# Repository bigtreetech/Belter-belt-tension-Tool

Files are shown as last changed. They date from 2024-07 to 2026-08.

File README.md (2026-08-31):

# BIQU Belter

Belter is a digital belt tension measurement tool for 3D printers, designed for belt setup, belt matching, and repeat adjustment.

## Quick Links

- **Product Link:** [BIGTREETECH Official Website](https://biqu.equipment/products/biqu-belter-belt-tension-tool)
- **Belter Calculation Tool:** [belter.bttwiki.com](https://belter.bttwiki.com/)
- **Calibration / Usage Guide:** [Belter Wiki](https://global.bttwiki.com/belter.html)
- **GitHub Link:** [bigtreetech/Belter-belt-tension-Tool](https://github.com/bigtreetech/Belter-belt-tension-Tool)

## Calibration & Calculation

The latest Belter workflow includes:

- Basic Belter calibration using **Belter Calibration Reading** and **Belt Thickness**
- **Compare Belts** and **Single Belt** measurement modes
- A default nonlinear tension model for normal use
- Optional **Calculation Model Calibration** using 500–2000 g test data for users who want the best possible absolute tension accuracy
- Preset or custom tension ranges in the Web Tool

For most users:

`Calibrate Belter → Measure Belts Normally`

For advanced users:

`Calibrate Belter → Optional Calculation Model Calibration → Measure Belts Normally`

## Repository Contents

- [`Calculation Tool`](./Calculation%20Tool/) — calculation and calibration resources
- [`Manual`](./Manual/) — English and Chinese Belter manuals
- [`PrintParts`](./PrintParts/) — STEP files for the Hand Held Bracket, Plunger, and ProbeTip
- [`LICENSE.md`](./LICENSE.md) — license information



## Copyright

These files and the designs contained therein are copyright (c) 2026 BIQU.

These files and the designs contained therein are additionally licensed under **CC-BY-NC-ND-4.0**.

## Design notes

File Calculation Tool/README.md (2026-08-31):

New calculator and calibration workflow are now available

## Belter Calculator & Documentation Update

We’ve made a major update to the **BIQU Belter calculation workflow, Web Tool, and documentation** based on community feedback and additional testing.

### What’s New

- **Updated tension calculation model**
  - The calculator now uses the nonlinear model:
    `Tension = A / (dmax - d)^p`
  - Default parameters have been updated 

- **Custom calculation model calibration**
  - Advanced users can now generate their own **Coefficient A** and **Exponent p** from real test data.
  - The Web Tool supports test loads from **500 g to 2000 g in 100 g increments**.
  - The fitted model automatically reports **R²** and **RMSE** for reference.

- **Calibration data spreadsheet**
  - A new spreadsheet is provided for recording repeated measurements.
  - Each load can be measured **12 times**.
  - The highest and lowest readings are automatically removed.
  - The remaining 10 readings are used to calculate **Average (trimmed 10)** and **StDev**.

- **Direct Excel → Web Tool data import**
  - Copy the complete **Average (trimmed 10)** row from the calibration spreadsheet.
  - Paste it into any field under **Fit Parameters from Test Data**.
  - The Web Tool automatically maps the values from **500 g → 2000 g** and runs the model fit.

- **Custom Tension Range**
  - The previous **Belt Width** setting has been updated to **Tension Range**.
  - Existing presets remain unchanged:
    - GT2 6 mm
    - GT2 9 mm
  - A new **Custom Range** option allows users to define their own **Min / Max tension** values.

- **English / Chinese language support**
  - The Web Tool can now be switched directly between **English and Chinese**.

- **Updated calibration workflow**
  - Normal Belter calibration remains simple.
  - Custom calculation model calibration is an **optional advanced step**.
  - Users who do not need a custom model can continue using the default calculation parameters.

### Recommended Workflow

`Calibrate Belter → [Optional] Calibrate Calculation Model → Measure Belts Normally`

The goal of this update is to make the Belter workflow more transparent, repeatable, and flexible while keeping normal day-to-day measurements simple.

Special thanks to **@rongith** for providing experimental measurement data and to **@anokfireball** for contributing to the nonlinear tension model and technical discussion.

We’ll continue improving the Belter workflow based on real-world testing and community feedback.

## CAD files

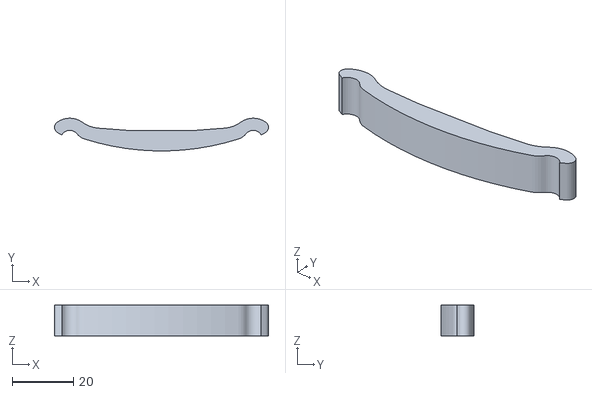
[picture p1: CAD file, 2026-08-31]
Calculation Tool/BIQU Belter Zeroing tool.STL
70.0 x 10.7 x 10.0

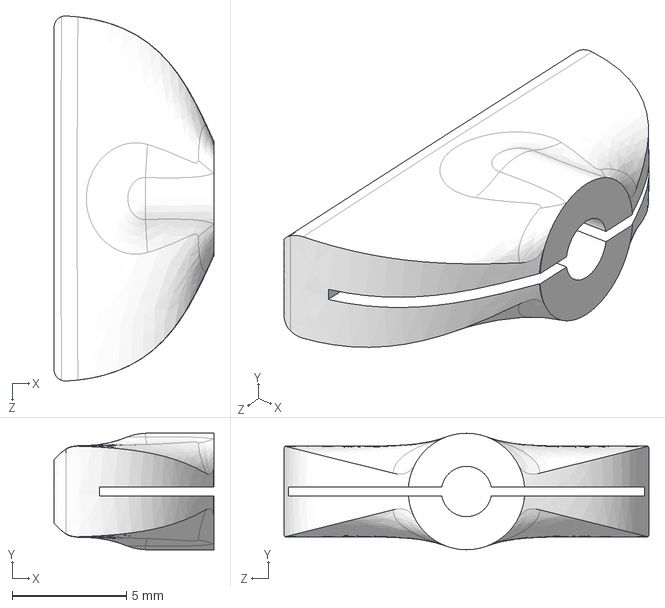
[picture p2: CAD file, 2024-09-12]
PrintParts/ProbeTip.STEP
7.00 x 5.10 x 16.0 mm

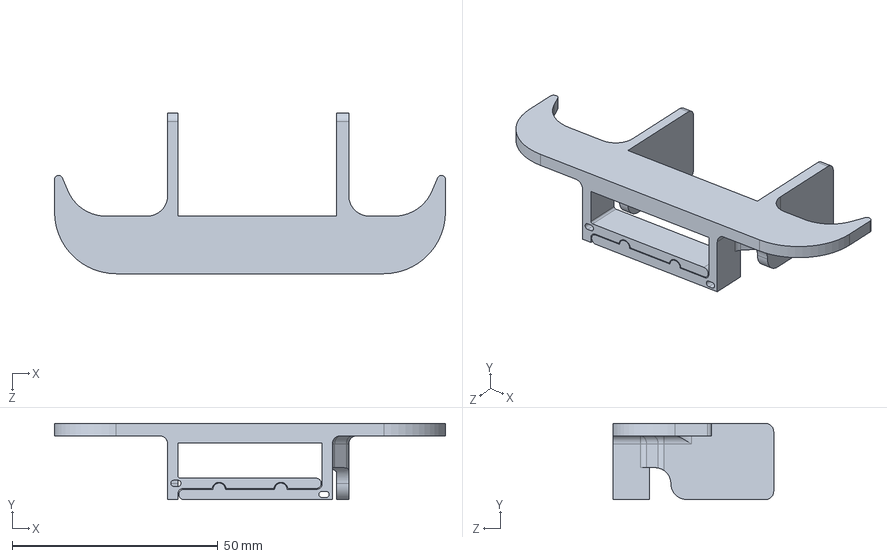
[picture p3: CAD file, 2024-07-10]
PrintParts/Hand Held bracket.STEP
95.0 x 18.5 x 39.0 mm

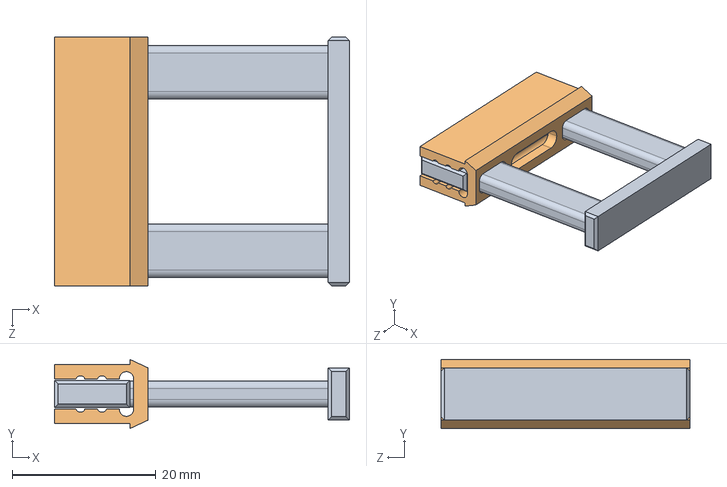
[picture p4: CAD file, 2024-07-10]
PrintParts/Plunger.STEP
41.0 x 9.60 x 34.6 mm

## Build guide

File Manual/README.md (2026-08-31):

# BIQU Belter Manual

The latest Belter setup, calibration, and usage instructions are maintained on the BIQU Wiki.

## View the Online Manual

👉 **[Open the BIQU Belter Wiki](https://global.bttwiki.com/belter.html)**

For the latest instructions and updates, please refer to the online Wiki instead of the files in this folder.

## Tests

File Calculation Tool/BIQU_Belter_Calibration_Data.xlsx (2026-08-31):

BIQU Belter Measurement Data
Enter 12 readings for each load. Average and StDev automatically exclude one highest and one lowest reading, using the remaining 10 values.
Measurement / Load | 500 g | 600 g | 700 g | 800 g | 900 g | 1000 g | 1100 g | 1200 g | 1300 g | 1400 g | 1500 g | 1600 g | 1700 g | 1800 g | 1900 g | 2000 g
Measurement 1 | 3.820 | 4.300 | 4.600 | 4.820 | 5.120 | 5.280 | 5.620 | 5.620 | 5.820 | 5.710 | 6.000 | 5.910 | 6.080 | 6.070 | 6.160 | 6.180
Measurement 2 | 4.000 | 4.380 | 4.620 | 4.950 | 5.000 | 5.230 | 5.410 | 5.550 | 5.920 | 5.880 | 6.030 | 5.890 | 6.080 | 6.190 | 6.150 | 6.190
Measurement 3 | 4.050 | 4.330 | 4.700 | 4.920 | 5.230 | 5.260 | 5.390 | 5.670 | 5.720 | 5.870 | 5.810 | 5.960 | 6.030 | 6.070 | 6.140 | 6.220
Measurement 4 | 3.920 | 4.400 | 4.810 | 4.760 | 5.230 | 5.290 | 5.500 | 5.580 | 5.720 | 5.710 | 5.890 | 5.950 | 6.110 | 6.130 | 6.160 | 6.280
Measurement 5 | 4.080 | 4.460 | 4.780 | 4.820 | 5.210 | 5.210 | 5.530 | 5.520 | 5.840 | 5.780 | 6.010 | 5.990 | 6.070 | 6.070 | 6.190 | 6.240
Measurement 6 | 3.820 | 4.300 | 4.640 | 4.840 | 5.010 | 5.290 | 5.510 | 5.580 | 5.740 | 5.790 | 5.921 | 5.960 | 6.100 | 6.110 | 6.180 | 6.230
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

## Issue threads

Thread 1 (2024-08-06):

Additional readings/tension calculator for other belt types?

netweaver1970, 2024-08-06:
Hi, can you provide the calculator for GT3 belts as well? My Monolith upgrade for my V2.4 will use 6mm GT3 belts.

Thanks!

BTTJUSTIN, 2024-09-11:
Thanks for making this suggestion. We will discuss it internally and update the documentation if it is approved.

zlatkomos, 2024-12-01:
> Thanks for making this suggestion. We will discuss it internally and update the documentation if it is approved.

.... do you have any news on this issue?

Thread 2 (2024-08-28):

Verify Belt Tensions...

LostFool, 2024-08-28:
Voron 2.4 r1
350mm
z belts = LL-2GT RF

Literally not possible to get them to the recommended ~7.05mm deflection.
Stuck at ~5.8

How can we determine these numbers to create our own belt charts?

SamppaD78, 2024-09-11:
No problem. Lets wait and see what support has to say.

V8coyote43v3r, 2024-09-12:
Update the Belt Tension GT2 RF (N)  values in colum b with actual tension, everything else will change automatically.

BTTJUSTIN, 2024-09-12:
Please print and install ProbeTip.step to ensure accurate reading
https://github.com/bigtreetech/Belter-belt-tension-Tool/tree/master/PrintParts

SamppaD78, 2024-09-12:
Hi. Installed the printed part and still max deflection of the belts is at -7.02 thats about 19.98N. Spec value is  20.04-25.8
I tried the B colum update values but nothing changes for me,only when values are updated on the belter displayed values chart is that i get the reading for tension.

rongith, 2024-09-13:
I have completely different values for a corresponding table mm / N.

I attached spools of filament of different weight to a suspended belt. Here my results:
| Spool weight (kg) | Spool weight (N) | My deflection (mm) | Biqu deflection (mm) |
| --- | --- | --- | --- |
| 0.325 | 3.19 | 3 | 4.8 |
| 0.565 | 5.54 | 4.4 | 5.1 |
| 0.861 | 8.45 | 5.2 | 5.5 |
| 1.130 | 11.1 | 5.7 | 5.8 |
| 1.580 | 15.5 | 6.1 | 6.4 |
| 1.935 | 18.9 | 6.3 | 6.9 |
| 2.305 | 22.6 | 6.4 | 7.3 |
| 3.205 | 31.4 | 6.7 | 8.5 |
| 4.255 | 41.7 | 6.9 | 9.8 |
| infinity | infinity | 7.6 | infinity |

How can the tension be proportional to the deflection according to your calculation sheet (you found a linear regression)? How can you reach 12mm deflection (under 58N tension) as with a straight belt, the deflection would be 7.6mm, the maximum value?

According to your linear regression, 1000N would be 135mm of deflection.

Something is very wrong here or I didn't understand at all how your equipment run.

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

SamppaD78, 2024-09-14:
Hi. I'm not a expert on belt tension. This info is what tool and calculator is providing . I purchased this belt tool to use it with tensioning Voron 2.4R2 belts. Now there is definitely a issue, is it a user ,tool,or calculator provided related I don't know,but we are here to find out. How I use this tool, zero out the tool,attach the tool to the belt and get the reading from the tool. Tool display -7,01 with plunger attached to the tools shaft.
I open the belt tension calculator,under printer type and model column  select Voron Z belts,under  Belter displayed value mm column I added  tool displayed value -7.01 and press enter. Calculator  Belt tension column display value of 20,075. Recommended tension column is showing recommended tension value of min 20.4 and max value of 25.8 and  last column is reporting that belt tension is out of range.
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

I would like to find reason for this issue,so help is appreciated.

SamppaD78, 2024-09-14:
I got email reply from BTT tech support on this issue

[support01@bigtree-tech.com,]

Hello sir, I asked about this kind of situation. Because the printout is installed or the printout itself or even the probe itself has differences, the actual measurement value will be inaccurate. We will set a standard in the future. Please wait patiently.

Looking forward to your reply.

Best Regards

Biqu

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

rongith, 2024-09-14:
> I would like to find reason for this issue,so help is appreciated.

Yes for me there is something wrong in the Biqu methodology. I made myself some measure to ensure I have some reliable results.

And would you know the "needle" go as far as intended in the probe tip? You may have an offset.

I designed the joined part as a reference to check I got every time 7.6mm (in my case) before measuring the belt. That way and because I done my own reference measurement, I'm quite independent of the probe tip print. It is like was have a straight belt 1.5mm thick. [Plat-r00b - Defaut.zip](https://github.com/user-attachments/files/17002922/Plat-r00b.-.Defaut.zip).

I don't understand how Biqu can have 9.22mm like in the manual. I got 7.6mm maximum.

SamppaD78, 2024-09-14:
Hi. You are right,I cant understand the way Biqu is thinking about this design,tool and way it should work. Thanks for providing zip file. I will print it and test when i get the time. Its a bysy time at work with long shifts ..

noonien, 2024-09-16:
I'm having the same issue, after calibrating to a 110Hz tune on the A/B belts, this tool reads a value of 5.5 - 5.6. The calculator is useless, therefore the tool is useless for measuring absolute tension.

It can, however, be used to measure relative tension, to ensure belts have the same tension, however, I've achieved basically the same thing using [this simple print](https://www.printables.com/model/135075-belt-tension-gauge).

Don't waste your money and time with this "tool".

SamppaD78, 2024-09-16:
You are right. Tool is worthless if you cant trust the calculator or the tool displayed values..waste of money and time . I was using this and it was working well for me. https://github.com/Diyshift/3D-Printer/tree/main/GT2%20Belt%20Tension%20Meter

BTTJUSTIN, 2024-09-19:
Hello，this is Justin from BTT, We have realized that there are errors in the calculation tool, Our engineers are hard at work trying to develope a new calculation tool to enable more accurate tension results, Please give us some time to remedy this issue, Thanks you for your patience.

LostFool, 2024-09-19:
> Hello，this is Justin from BTT, We have realized that there are errors in the calculation tool, Our engineers are hard at work trying to develope a new calculation tool to enable more accurate tension results, Please give us some time to remedy this issue, Thanks you for your patience.

Thank you for looking into the issue. I will eagerly awate the update.
I know it's hard with so many variables

SamppaD78, 2024-09-19:
Hi. Nice to see that someone is taking this issue seriously , and is making effort to solve this issue. Thanks BTJustin,we will wait for a solution.

reneleban, 2024-09-27:
Hello,
the biggest problem seems to be the printed part, and how deep to insert the pin.
If you push all the way to the bottom, I'm at 7.84. With the printed part from rongith, if I just insert it until the resistance of the printed part rises, I have a value of 9.38.

Maybe a printed part like that and a “reference value” to convert the effective measurement in Excel could be the solution.

btt could print the part, measure the reference value for the given values in the table,
we print the part and could insert the measured value in a specific field, and the “belt display value” for the calculation of the “belt tension” field could be converted in the calculations.
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
miamijerry, 2025-01-24:
Yes, I will post to Github.

Working on version 2, Github is mostly done for version 1

miamijerry, 2025-01-24:
https://github.com/miamijerry/Direct-Reading-GT2-Belt-Tension-Gauge/tree/main

Testing V2, so no STL's until they are completely tested

miamijerry, 2025-01-25:
Files are uploaded

https://github.com/miamijerry/Direct-Reading-GT2-Belt-Tension-Gauge/blob/main/README.md

auggie246, 2025-02-10:
Have you verified that your tool is indeed measuring the correct values?

> Files are uploaded
>
> https://github.com/miamijerry/Direct-Reading-GT2-Belt-Tension-Gauge/blob/main/README.md

imightbelosthere, 2025-03-03:
> Does the BIQU thing finally work? I ordered one ....

Unfortunately you were scammed like the lot of us...
Biqu doesn't care, won't fix the scale of measurement.

ErockSaint, 2025-03-07:
> Does the BIQU thing finally work? I ordered one ....

Return it. I ended up in the hospital, then laid up for weeks at home, so I missed my amazon return window. Guess I just have a fancy paperweight now.

Bata3, 2025-03-13:
Any update to the calculator? A new version was supposed to be released in January, today is March and still nothing.

SamppaD78, 2025-03-15:
No update...Best solution print a gt2 tension tool and use it to tighten the belts .  BTT  should  issue a recall with a refund. Many of us are waiting for long time now for this problem to be resolved and BTT is still selling this crap .

blackjack121079, 2025-04-03:
+1 deceived. Btt, aren't you ashamed? You took the money, but where is the result?

micvog, 2025-04-29:
It's nearly May and still nothing. I have quite a few biqu components in my Voron, this is very disappointing and I'll look at other vendors in the future.

> > Any updates on calculation tool? I do not want to over-tight the belts or remove completely belts to reduce the tightens because of wrong excel file, currently it is showing me (without any tension applied on 2.4 R2) that all my belts are over-tighten... This tool should make our life easier not worse.
>
> The new calculation tool is done. We are just performing some final verification measurements and then we will release should be early next week.

@bigtreetech What happened since this "update"?

SamppaD78, 2025-05-02:
Nothing happend with that update,that's the problem. Many of us use BTT hardware on the printers and still BTT support is not to task solving issues with the BTT products. After all the waiting i decided to stop purchasing BTT products as customer support is not doing the job fixing issueswith BTT products and all the end user gets from them is empty promises. I adjusted Voron 2.4R2 gates belts using Lazer timing belt tool and compare the values with BTT tension tool.  For AB belts tension  7,5-15N  this is about 2lb->110Hz-> Belter tension tool values 10N=-5.70mm 15N=-6.00mm
Z belts recommended tension is 20,4-25,8N in Hz-> 140Hz.
Belter tester corresponding values for Z belts  20N-> -6.50mm  25N-> -6.70mm
I hope this info helps .

miamijerry, 2025-05-02:
There is a method by which this belter tool could give belt tension numbers in pounds or neutons.

1) Replace belt pivot points for Belt bearing pulleys
2) Create a new xlsx or multiple xlsx sheets that call out a "Length of the span"
3) Calibrate the depth readings of the Belter to actual belt tension.

Like one chart for 10 inch span, 11 inch span, etc...

Issue was assuming span length did not need to be part of the original xlsx

BackwardEcho, 2025-05-08:
Has anyone with that [RC2 Belt Tensioner](https://github.com/Diyshift/3D-Printer/tree/main/GT2%20Belt%20Tension%20Meter) previously mentioned tried measuring other metals / rods / wires from K&S Precision Metals? If a handful can be found that match the specific values given in the "Tension Guidelines", then those could be measured against with the BIQU. It wont give the N value like I was hoping to have when I very recently bought this thing, but it should help in obtaining a repeatable outcome from tensioning with the BIQU Belter. I plan to go buy some 5501 Piano Wire in the next few days so I at least have something to work with for now.

micvog, 2025-09-29:
I'm sorry, I'm not going to let this go. If this was a product that was out of production and support doesn't makes sense, fine. But this thing is STILL being sold, even though it's essentially useless without a way to properly interpret the reading.
@bigtreetech You promised that the new version of the spreadsheet was done. That was January 2. It is now October, and not a peep out of you. This is unacceptable, and I've personally steered 3 people away from your products that were interested in 3d printing already, and I will continue to do so until you fix your product.

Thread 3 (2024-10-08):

Belter_tension_calculator Tool

KA009onPC, 2024-10-08:
when i go to open this, its just a blank page?

BTTJUSTIN, 2024-10-09:
Thanks for reaching out. Our support team does not operate using the GitHub platform but we would be happy to help you via email based ticketing system. Please visit https://biqu.equipment/pages/technical-support
and submit a ticket and we will be in touch with you soon.

bigtreetech, 2024-10-09:
> when i go to open this, its just a blank page?

Make sure that you are not right clicking and saying download. You need to use the github method of downloading using the arrow icon. If you right click, the file will be corrupt.

KA009onPC, 2024-10-09:
Could you please send screen shots of how to install this? I don't know where to go

________________________________
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

bigtreetech, 2024-10-09:
> Could you please send screen shots of how to install this? I don't know where to go
> […](#)
> ________________________________ From: BIGTREETECH ***@***.***> Sent: Wednesday, October 9, 2024 5:40:42 AM To: bigtreetech/Belter-belt-tension-Tool ***@***.***> Cc: KA009onPC ***@***.***>; Author ***@***.***> Subject: Re: [bigtreetech/Belter-belt-tension-Tool] Belter_tension_calculator Tool (Issue #3) when i go to open this, its just a blank page? Make sure that you are not right clicking and saying download. You need to use the github method of downloading using the arrow icon. If you right click, the file will be corrupt. — Reply to this email directly, view it on GitHub<[#3 (comment)](https://github.com/bigtreetech/Belter-belt-tension-Tool/issues/3#issuecomment-2401836927)>, or unsubscribe<https://github.com/notifications/unsubscribe-auth/BFVMGG4JE7WQU6YM6EHCOQ3Z2T2ZVAVCNFSM6AAAAABPRA3HA2VHI2DSMVQWIX3LMV43OSLTON2WKQ3PNVWWK3TUHMZDIMBRHAZTMOJSG4>. You are receiving this because you authored the thread.Message ID: ***@***.***>

It's an excel spreadsheet.

KA009onPC, 2024-10-09:
Okay im so sorry.. my pc doesn't have excel that's why...

________________________________
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

KA009onPC, 2024-10-09:
Is this calculator good for 9mm belts?

________________________________
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

Closed 2024-10-09.

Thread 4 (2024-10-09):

Cant figure out how to download belt Tension calculator

KA009onPC, 2024-10-09:
Could you please send screen shots of how to install this please?

BTTJUSTIN, 2024-10-11:
Thanks for reaching out. Our support team does not operate using the GitHub platform but we would be happy to help you via email based ticketing system. Please visit https://biqu.equipment/pages/technical-support
and submit a ticket and we will be in touch with you soon.

Closed 2024-10-18.

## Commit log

2024-07-24 update manual
    [Belter_tension_calculator.xlsx, Tension Calculator.xlsx, 皮带拉力计算器.xlsx]
2024-07-24 Belter_tension_calculator.xlsx tool
    [Belter_tension_calculator.xlsx]
2024-09-12 replace ProbeTip
    [ProbeTip.STEP, ProbeTip.stl]
2026-08-31 update tool
    [BIQU Belter Zeroing tool.STL, BIQU_Belter_Calibration_Data.xlsx, Belter_tension_calculator.xlsx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]

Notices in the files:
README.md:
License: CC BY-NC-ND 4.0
